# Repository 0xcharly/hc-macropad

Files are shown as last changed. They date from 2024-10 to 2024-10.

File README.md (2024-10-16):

<div align="center">


</div>

---

# HC Macropad

PCB for HC Macropad event.

## BOM

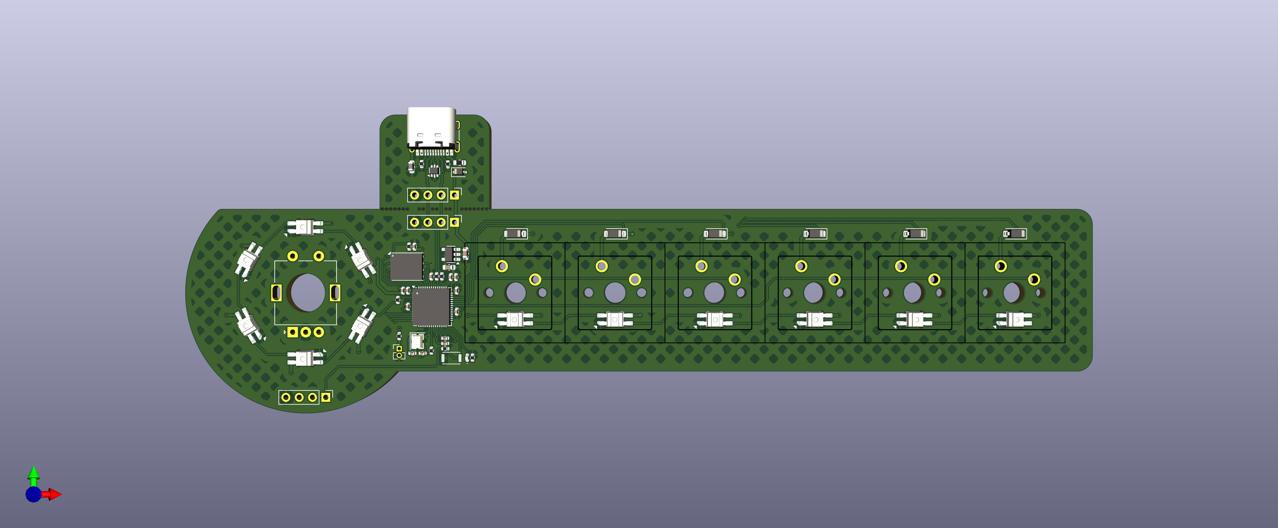
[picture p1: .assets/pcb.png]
PCB


- 1× EC11 rotary encoder
- 6× MX switches
- 6× SOD123 diodes
- (optional) 12× SK6812 Mini-E LEDs

## 3D Model

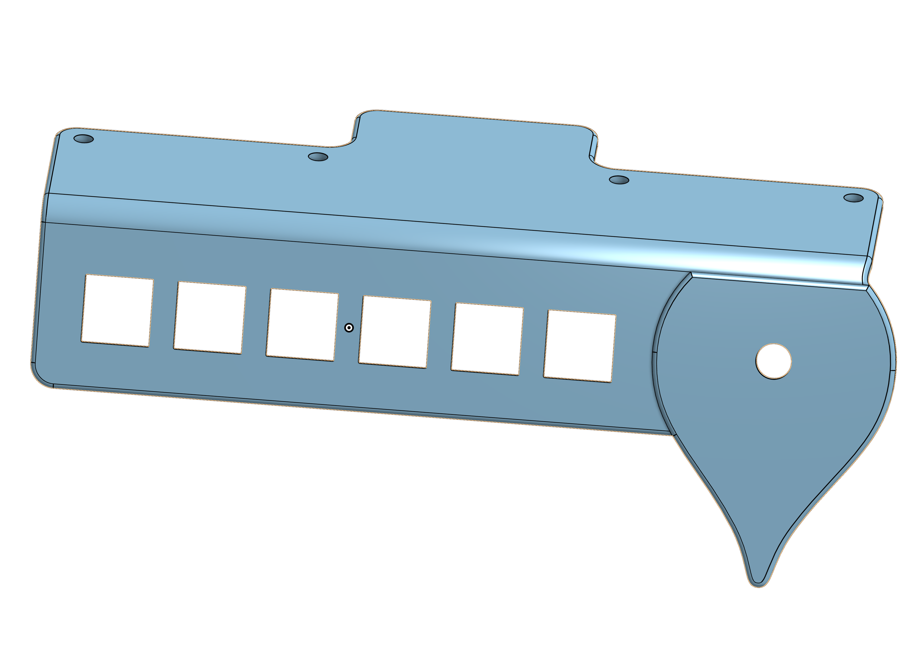
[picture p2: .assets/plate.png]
3D Model


The 3D model was designed with [OnShape](https://onshape.com) and is available
[publicly](https://cad.onshape.com/documents/3070554cf94c5dc376b0a8a4/w/4d0968bd551d0635d2f8d7e6/e/86d2deca2d0d715bf15eadd2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).

## Firmware

The firmware is powered by [QMK](https://qmk.fm) and can be found in
[0xcharly/qmk_firmware](https://github.com/0xcharly/qmk_firmware/tree/hc-macropad)
on the `hc-macropad` branch.

The keyboard and keymap are defined under `keyboards/hc_macropad` and can be
built using the QMK CLI:

```sh
qmk compile -kb hc_macropad -km default
```

See the
[README.md](https://github.com/0xcharly/qmk_firmware/blob/hc-macropad/keyboards/hc_macropad/readme.md)
for more information.

## First prototypes

The encoder case footprint needs some work…

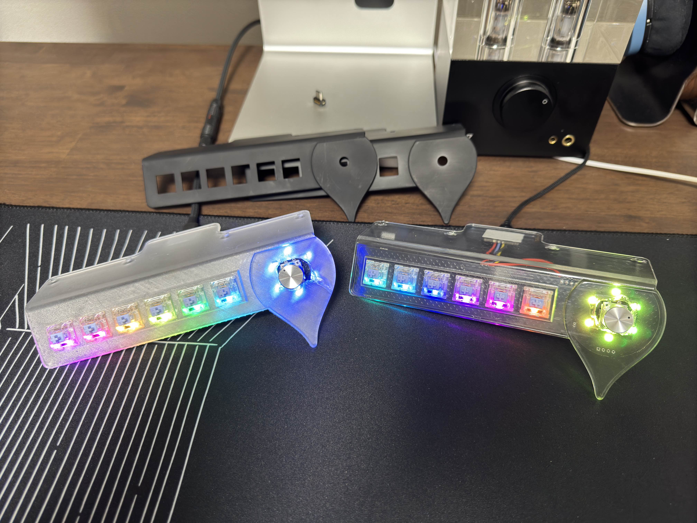
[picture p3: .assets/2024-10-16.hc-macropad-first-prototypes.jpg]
First prototypes


## Credits

The PCB design, and specifically the RP2040-based controller is based off the
work of [Bastard Keyboards](https://bastardkb.com), adapted from their
[Dilemma](https://github.com/Bastardkb/Dilemma) design.

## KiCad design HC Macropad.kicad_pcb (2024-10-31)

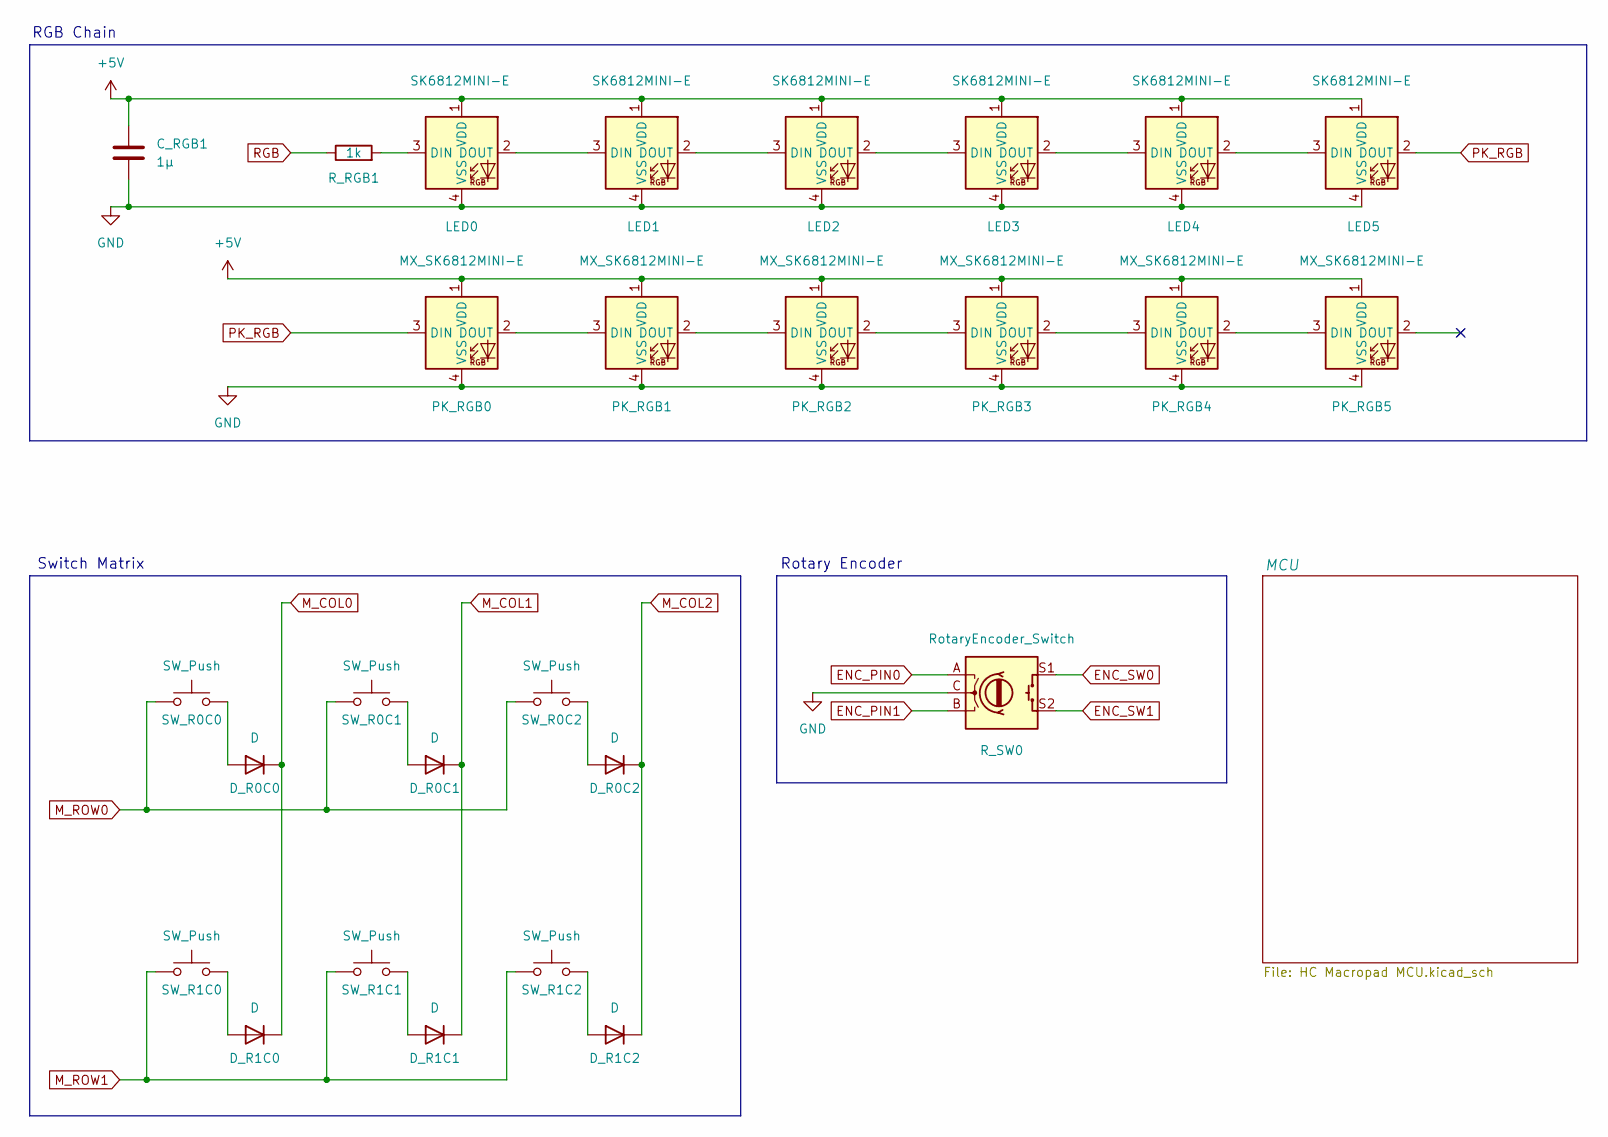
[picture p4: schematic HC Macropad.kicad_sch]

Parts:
C_RGB1: 1µ; C_0402_1005Metric; LCSC C52923
D_R0C0, D_R0C1, D_R0C2, D_R1C0, D_R1C1, D_R1C2: D; D_SOD-123; LCSC C571353
LED0, LED1, LED2, LED3, LED4, LED5: SK6812MINI-E; LED_6028R; LCSC C5149201
PK_RGB0, PK_RGB1, PK_RGB2, PK_RGB3, PK_RGB4, PK_RGB5: MX_SK6812MINI-E; LED_MX_6028R; LCSC C5149201
R_RGB1: 1k; R_0402_1005Metric; LCSC C11702
R_SW0: RotaryEncoder_Switch; RotaryEncoder_Alps_EC11E-Switch_Vertical_H20mm
SW_R0C0, SW_R0C1, SW_R0C2, SW_R1C0, SW_R1C1, SW_R1C2: SW_Push; SW_MX_1u

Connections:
+5V: C_RGB1.1, LED0.1 (VDD), LED1.1 (VDD), LED2.1 (VDD), LED3.1 (VDD), LED4.1 (VDD), LED5.1 (VDD), PK_RGB0.1 (VDD), PK_RGB1.1 (VDD), PK_RGB2.1 (VDD), PK_RGB3.1 (VDD), PK_RGB4.1 (VDD), PK_RGB5.1 (VDD); also elsewhere on the board
ENC_PIN0: R_SW0.A; also elsewhere on the board
ENC_PIN1: R_SW0.B; also elsewhere on the board
ENC_SW0: R_SW0.S1; also elsewhere on the board
ENC_SW1: R_SW0.S2; also elsewhere on the board
GND: C_RGB1.2, LED0.4 (VSS), LED1.4 (VSS), LED2.4 (VSS), LED3.4 (VSS), LED4.4 (VSS), LED5.4 (VSS), PK_RGB0.4 (VSS), PK_RGB1.4 (VSS), PK_RGB2.4 (VSS), PK_RGB3.4 (VSS), PK_RGB4.4 (VSS), PK_RGB5.4 (VSS), R_SW0.C; also elsewhere on the board
M_COL0: D_R0C0.1 (K), D_R1C0.1 (K); also elsewhere on the board
M_COL1: D_R0C1.1 (K), D_R1C1.1 (K); also elsewhere on the board
M_COL2: D_R0C2.1 (K), D_R1C2.1 (K); also elsewhere on the board
M_ROW0: SW_R0C0.1, SW_R0C1.1, SW_R0C2.1; also elsewhere on the board
M_ROW1: SW_R1C0.1, SW_R1C1.1, SW_R1C2.1; also elsewhere on the board
unnamed: D_R0C0.2 (A), SW_R0C0.2
unnamed: D_R0C1.2 (A), SW_R0C1.2
unnamed: D_R0C2.2 (A), SW_R0C2.2
unnamed: D_R1C0.2 (A), SW_R1C0.2
unnamed: D_R1C1.2 (A), SW_R1C1.2
unnamed: D_R1C2.2 (A), SW_R1C2.2
unnamed: LED0.3 (DIN), R_RGB1.2
unnamed: LED0.2 (DOUT), LED1.3 (DIN)
unnamed: LED1.2 (DOUT), LED2.3 (DIN)
unnamed: LED2.2 (DOUT), LED3.3 (DIN)
unnamed: LED3.2 (DOUT), LED4.3 (DIN)
unnamed: LED4.2 (DOUT), LED5.3 (DIN)
unnamed: PK_RGB0.2 (DOUT), PK_RGB1.3 (DIN)
unnamed: PK_RGB1.2 (DOUT), PK_RGB2.3 (DIN)
unnamed: PK_RGB2.2 (DOUT), PK_RGB3.3 (DIN)
unnamed: PK_RGB3.2 (DOUT), PK_RGB4.3 (DIN)
unnamed: PK_RGB4.2 (DOUT), PK_RGB5.3 (DIN)
PK_RGB: LED5.2 (DOUT), PK_RGB0.3 (DIN)
RGB: R_RGB1.1; also elsewhere on the board

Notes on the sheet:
Switch Matrix
RGB Chain
Rotary Encoder

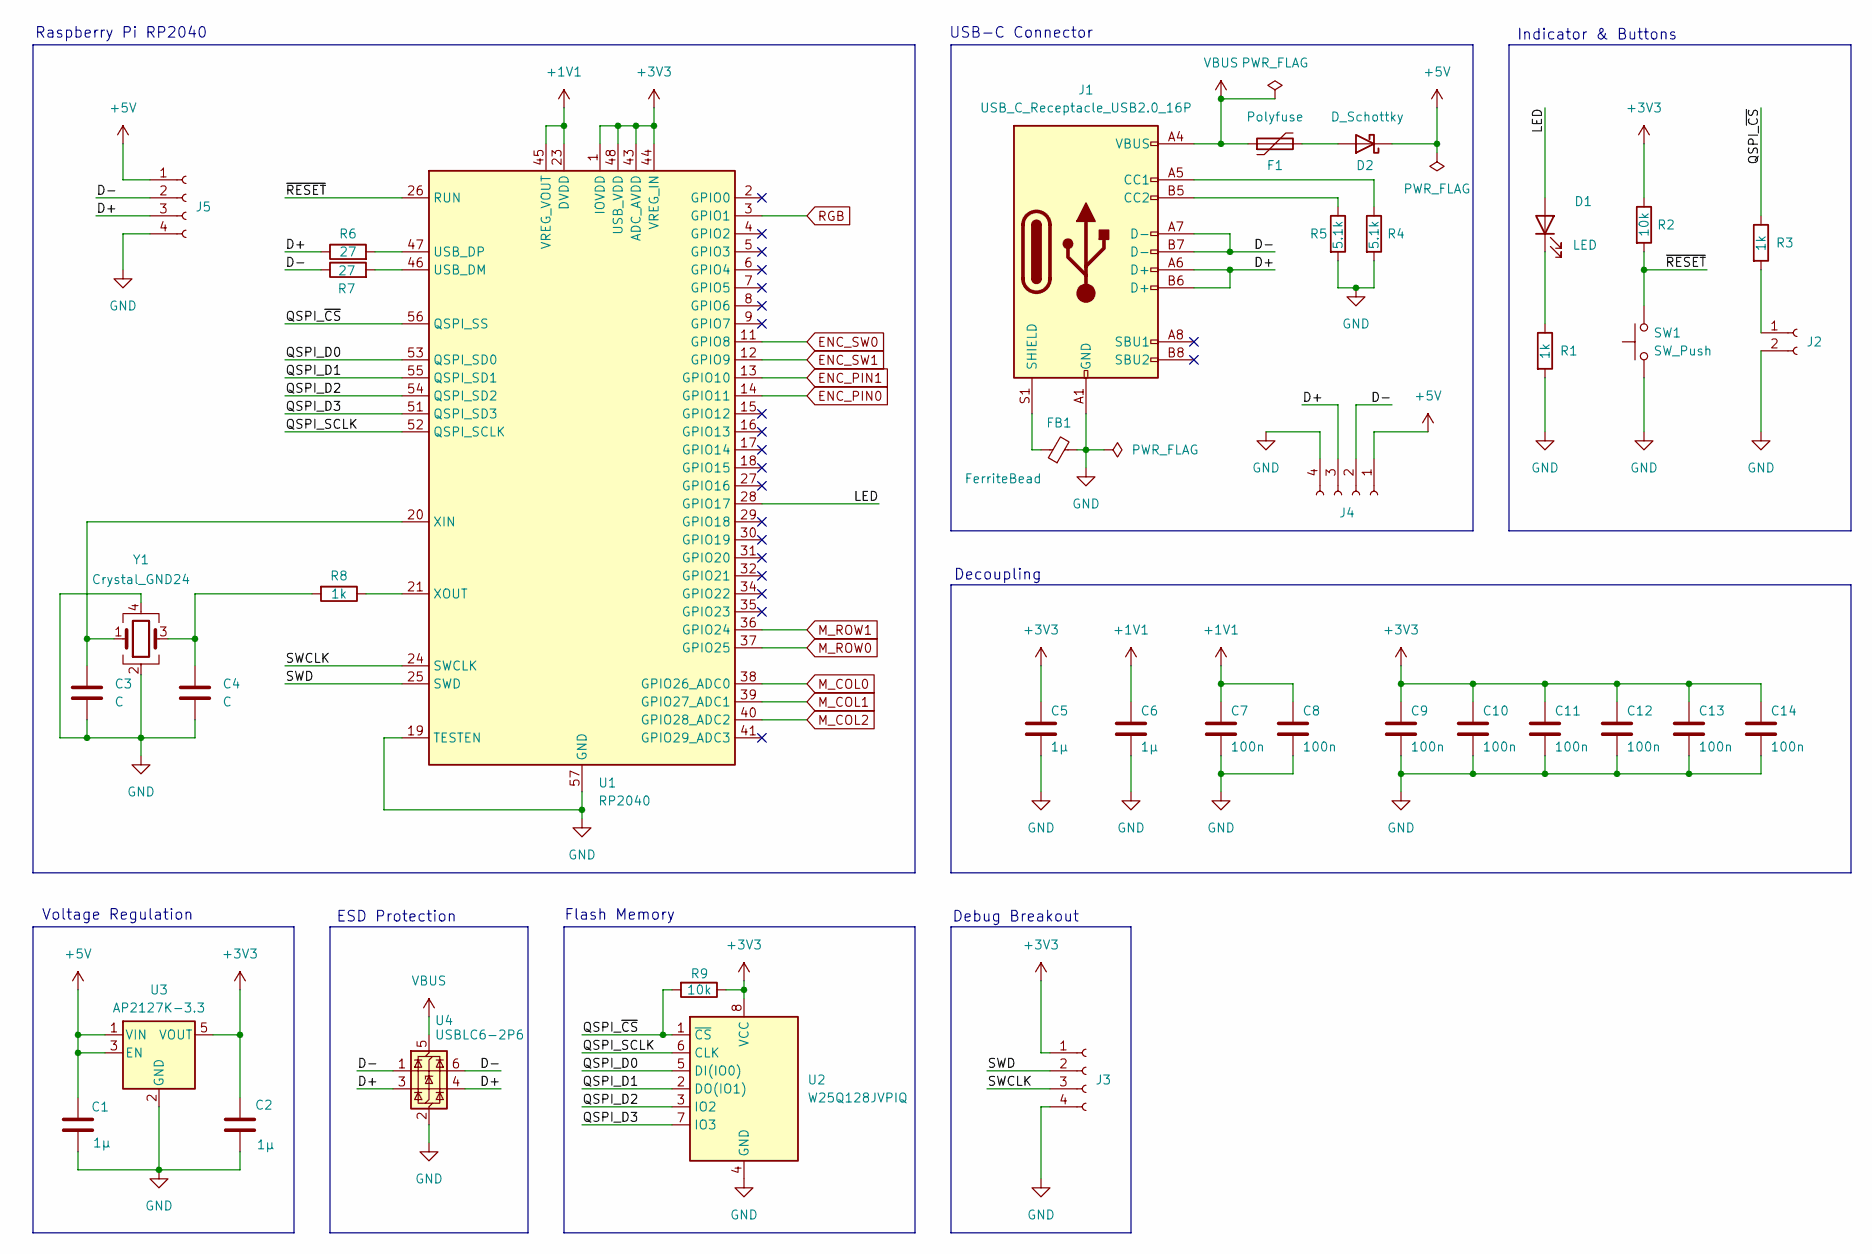
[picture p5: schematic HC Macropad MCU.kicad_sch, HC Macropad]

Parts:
C1, C2: 1µ; C_0603_1608Metric; LCSC C19666
C3, C4: C; C_0402_1005Metric; LCSC C1548
C5, C6: 1µ; C_0402_1005Metric; LCSC C52923
C7, C8, C9, C10, C11, C12, C13, C14: 100n; C_0402_1005Metric; LCSC C1525
D1: LED; LED_0402_1005Metric; LCSC C130719
D2: D_Schottky; D_SOD-323; LCSC C123899
F1: Polyfuse; Fuse_0603_1608Metric; LCSC C69679
FB1: FerriteBead; L_0603_1608Metric; LCSC C98288
J1: USB_C_Receptacle_USB2.0_16P; USB_C_Receptacle_HRO_TYPE-C-31-M-12; LCSC C165948
J2: Conn_01x02_Socket; PinHeader_1x02_P1.27mm_Vertical
J3, J4, J5: Conn_01x04_Socket; PinHeader_1x04_P2.54mm_Vertical
R1, R3, R8: 1k; R_0402_1005Metric; LCSC C11702
R2, R9: 10k; R_0402_1005Metric; LCSC C25744
R4, R5: 5.1k; R_0402_1005Metric; LCSC C25905
R6, R7: 27; R_0402_1005Metric; LCSC C25100
SW1: SW_Push; SW_SPST_CK_KXT3; LCSC C319433
U1: RP2040; QFN-56-1EP_7x7mm_P0.4mm_EP3.2x3.2mm; LCSC C2040
U2: W25Q128JVPIQ; WSON-8-1EP_6x5mm_P1.27mm_EP3.4x4.3mm; LCSC C190862
U3: AP2127K-3.3; SOT-23-5; LCSC C82942
U4: USBLC6-2P6; SOT-666; LCSC C2827693
Y1: Crystal_GND24; Crystal_SMD_2520-4Pin_2.5x2.0mm; LCSC C2149204

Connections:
+1V1: C6.1, C7.1, C8.1, U1.23 (DVDD), U1.45 (VREG_VOUT), U1.50 (DVDD)
+3V3: C2.1, C5.1, C9.1, C10.1, C11.1, C12.1, C13.1, C14.1, J3.1, R2.1, R9.1, U1.1 (IOVDD), U1.10 (IOVDD), U1.22 (IOVDD), U1.33 (IOVDD), U1.42 (IOVDD), U1.43 (ADC_AVDD), U1.44 (VREG_IN), U1.48 (USB_VDD), U1.49 (IOVDD), U2.8 (VCC), U3.5 (VOUT)
+5V: C1.1, D2.1 (K), J4.1, J5.1, U3.1 (VIN), U3.3 (EN); also elsewhere on the board
/MCU/D+: J1.A6 (D+), J1.B6 (D+), J4.3, J5.3, R6.1, U4.3 (I/O2), U4.4 (I/O2)
/MCU/D-: J1.A7 (D-), J1.B7 (D-), J4.2, J5.2, R7.1, U4.1 (I/O1), U4.6 (I/O1)
/MCU/LED: D1.2 (A), U1.28 (GPIO17)
/MCU/QSPI_D0: U1.53 (QSPI_SD0), U2.5 (DI(IO0))
/MCU/QSPI_D1: U1.55 (QSPI_SD1), U2.2 (DO(IO1))
/MCU/QSPI_D2: U1.54 (QSPI_SD2), U2.3 (IO2)
/MCU/QSPI_D3: U1.51 (QSPI_SD3), U2.7 (IO3)
/MCU/QSPI_SCLK: U1.52 (QSPI_SCLK), U2.6 (CLK)
/MCU/QSPI_~CS: R3.1, R9.2, U1.56 (QSPI_SS), U2.1 (~CS)
/MCU/SWCLK: J3.3, U1.24 (SWCLK)
/MCU/SWD: J3.2, U1.25 (SWD)
/MCU/~RESET: R2.2, SW1.2, U1.26 (RUN)
ENC_PIN0: U1.14 (GPIO11); also elsewhere on the board
ENC_PIN1: U1.13 (GPIO10); also elsewhere on the board
ENC_SW0: U1.11 (GPIO8); also elsewhere on the board
ENC_SW1: U1.12 (GPIO9); also elsewhere on the board
GND: C1.2, C2.2, C3.2, C4.2, C5.2, C6.2, C7.2, C8.2, C9.2, C10.2, C11.2, C12.2, C13.2, C14.2, FB1.2, J1.A1 (GND), J1.A12 (GND), J1.B1 (GND), J1.B12 (GND), J2.2, J3.4, J4.4, J5.4, R1.2, R4.2, R5.2, SW1.1, U1.19 (TESTEN), U1.57 (GND), U2.4 (GND), U3.2 (GND), U4.2 (GND), Y1.2, Y1.4; also elsewhere on the board
M_COL0: U1.38 (GPIO26_ADC0); also elsewhere on the board
M_COL1: U1.39 (GPIO27_ADC1); also elsewhere on the board
M_COL2: U1.40 (GPIO28_ADC2); also elsewhere on the board
M_ROW0: U1.37 (GPIO25); also elsewhere on the board
M_ROW1: U1.36 (GPIO24); also elsewhere on the board
unnamed: C4.1, R8.2, Y1.3
unnamed: D1.1 (K), R1.1
unnamed: D2.2 (A), F1.2
unnamed: J1.A5 (CC1), R4.1
unnamed: J1.B5 (CC2), R5.1
unnamed: FB1.1, J1.S1 (SHIELD)
unnamed: J2.1, R3.2
unnamed: R7.2, U1.46 (USB_DM)
unnamed: R6.2, U1.47 (USB_DP)
unnamed: C3.1, U1.20 (XIN), Y1.1
unnamed: R8.1, U1.21 (XOUT)
RGB: U1.3 (GPIO1); also elsewhere on the board
VBUS: F1.1, J1.A4 (VBUS), J1.A9 (VBUS), J1.B4 (VBUS), J1.B9 (VBUS), U4.5 (VBUS)

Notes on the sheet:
Indicator & Buttons
Voltage Regulation
Flash Memory
Raspberry Pi RP2040
Decoupling
ESD Protection
Debug Breakout
USB-C Connector

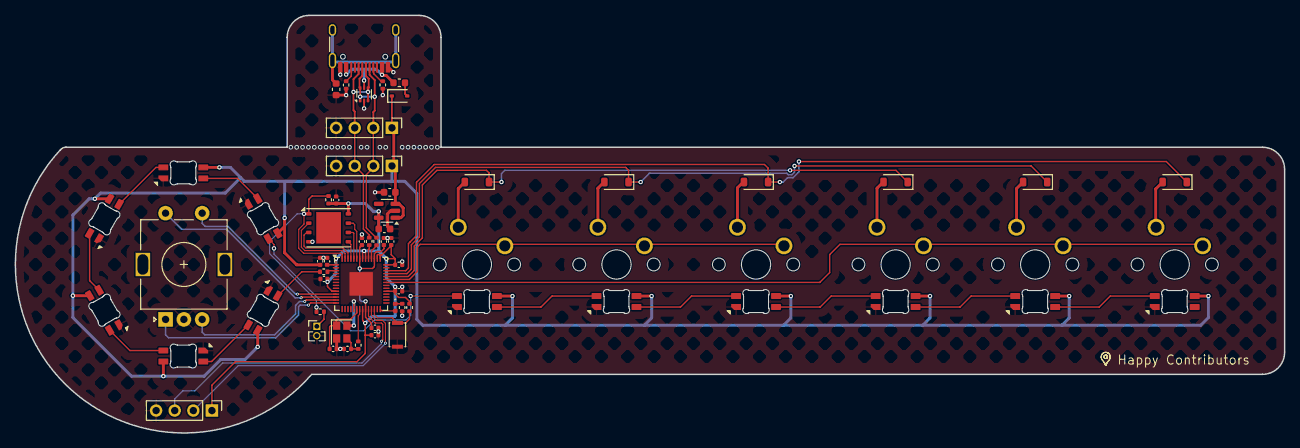
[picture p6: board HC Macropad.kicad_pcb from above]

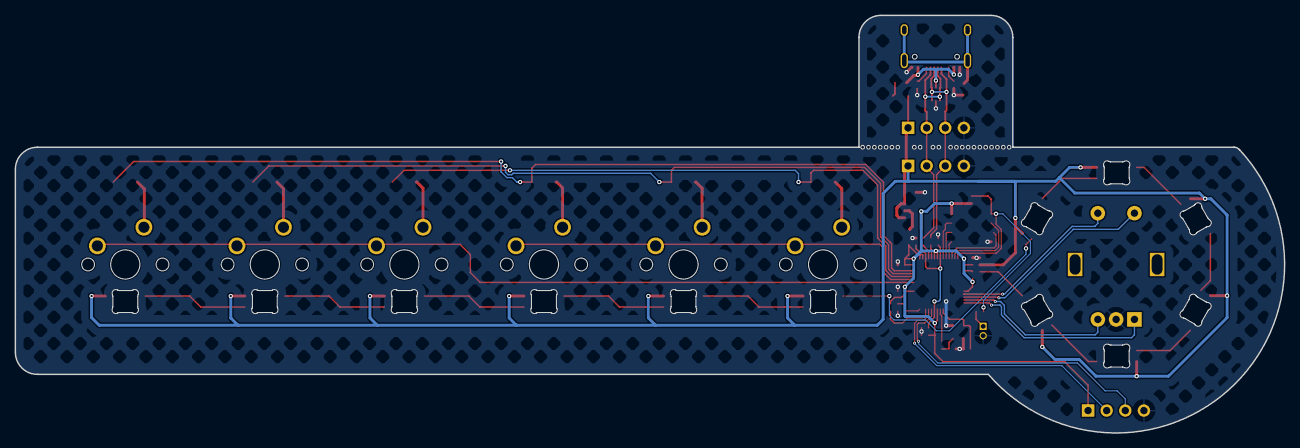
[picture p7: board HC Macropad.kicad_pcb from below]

Board: 2 copper layers, 173.2 x 57.0 mm, 65 parts (6 on the bottom side), 56 nets.

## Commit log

2024-10-02 Initial commit: v0.1.1
    [HC Macropad MCU.kicad_sch, HC Macropad.kicad_pcb, HC Macropad.kicad_sch]
2024-10-03 Starting to work on the PCB, might need to enlarge it
    [HC Macropad.kicad_pcb, HC Macropad.kicad_sch]
2024-10-05 Move switches, diodes, and LEDs to their final location
    [HC Macropad.kicad_pcb]
2024-10-06 90% of routing done
    [HC Macropad MCU.kicad_sch, HC Macropad.kicad_pcb]
2024-10-06 Finished routing
    [HC Macropad.kicad_pcb]
2024-10-06 Remove all remaining warnings
    [HC Macropad.kicad_pcb]
2024-10-07 Pack flash a little bit more closer to the rest of the MCU components to give as much clearance to the handsolder components as possible
    [HC Macropad.kicad_pcb]
2024-10-07 Minor trace touch up
    [HC Macropad.kicad_pcb]
2024-10-07 Update comments and LICENCE file to CERN Open Hardware Licence v2
    [HC Macropad MCU.kicad_sch, HC Macropad.kicad_pcb, HC Macropad.kicad_sch]
2024-10-07 Mark connectors as 'Do not populate'
    [HC Macropad.kicad_pcb]
2024-10-07 Minor routing changes
    [HC Macropad.kicad_pcb]
2024-10-07 Minor changes before production
    [HC Macropad.kicad_pcb, HC Macropad.kicad_sch]
2024-10-16 Add pictures of first prototypes
2024-10-16 I'm hilarious…
2024-10-30 v0.1.3: UFE edition
    [HC Macropad MCU.kicad_sch, HC Macropad.kicad_pcb, HC Macropad.kicad_sch]
2024-10-30 v0.1.4: HC edition
    [HC Macropad.kicad_pcb]
2024-10-31 v0.1.5: finalized HC edition
    [HC Macropad.kicad_pcb]

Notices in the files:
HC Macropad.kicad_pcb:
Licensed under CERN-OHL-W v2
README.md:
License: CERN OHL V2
